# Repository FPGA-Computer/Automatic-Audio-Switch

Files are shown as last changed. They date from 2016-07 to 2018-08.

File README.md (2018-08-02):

"Automatic audio source switching"

This is the repository for this project.

Project page:
http://hw-by-design.blogspot.com/2018/08/automatic-audio-source-switching.html

Schematic tool: Eagle CAD 6.5.0
3D modelling: Sketchup 14.1 2014

The main PCB is for single sided toner transfer.  If you wish to make a double sided
PCB, just copy the ground pour from the secondardy side to primary side.  I have already
defined a ground split on tRestrict layer.

Licensing:
Schematic: Creative Commons 4.0 Attribution-ShareAlike 4.0 International
PCB & Layout: Creative Commons 4.0 Attribution-NonCommercial
3D modelling: Creative Commons 4.0 Attribution-ShareAlike 4.0 International

Creative Commons 4.0 Attribution-NonCommercial:
See http://creativecommons.org/licenses/by-nc/4.0/

Creative Commons 4.0 Attribution-ShareAlike 4.0 International
See http://creativecommons.org/licenses/by-sa/4.0/

Firmware (Keil MDK)
license: GPL 3.0

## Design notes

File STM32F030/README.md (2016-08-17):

"Automatic audio source switching"

file: startup_stm32f030.s, intfft.c and intfft.h 
are not mine and they have their own licenses.

The rest of the firmware is under GPL 3.0

release log:

Aug 17, 2016 - pre-release
My PCB order has been lost in the mail twice in a row so far
and it has been holding up the progress of this project.

I don't know when I'll have final hardware for full testing.

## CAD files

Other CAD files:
Eagle CAD/Sketchup 3D/daughtercard-assembly.skp
Eagle CAD/Sketchup 3D/daughtercard.skp

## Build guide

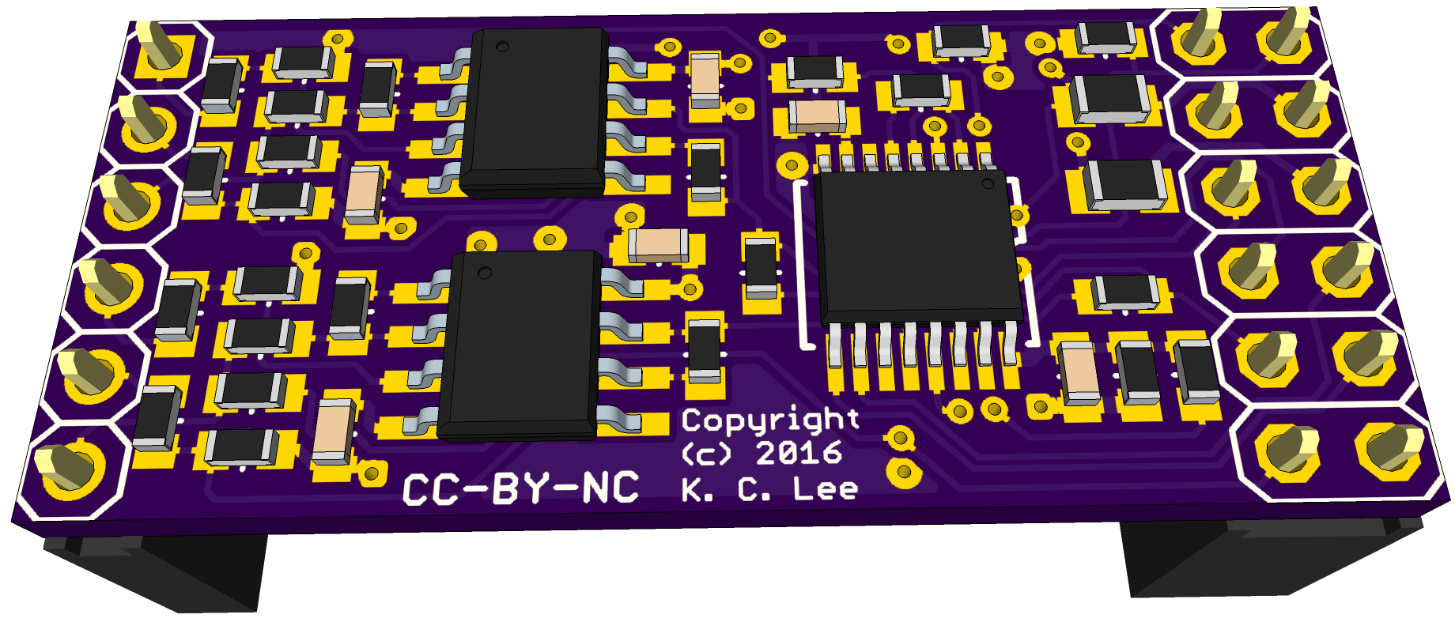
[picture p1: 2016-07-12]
Eagle CAD/Sketchup 3D/daughtercard-assembly.png

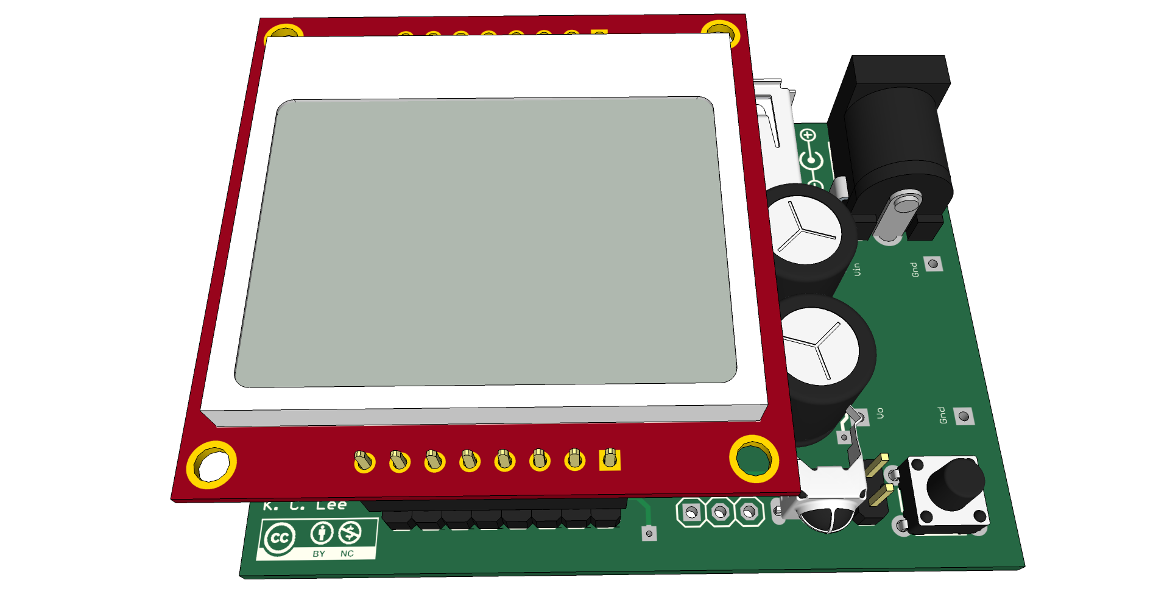
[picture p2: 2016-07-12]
Eagle CAD/Sketchup 3D/assembly.png

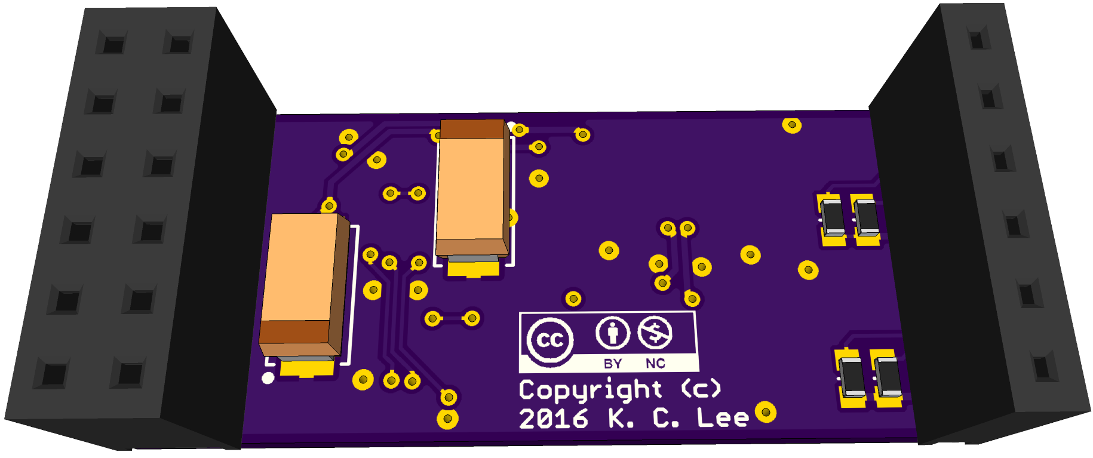
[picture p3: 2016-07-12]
Eagle CAD/Sketchup 3D/daughtercard-assembly-bot.png

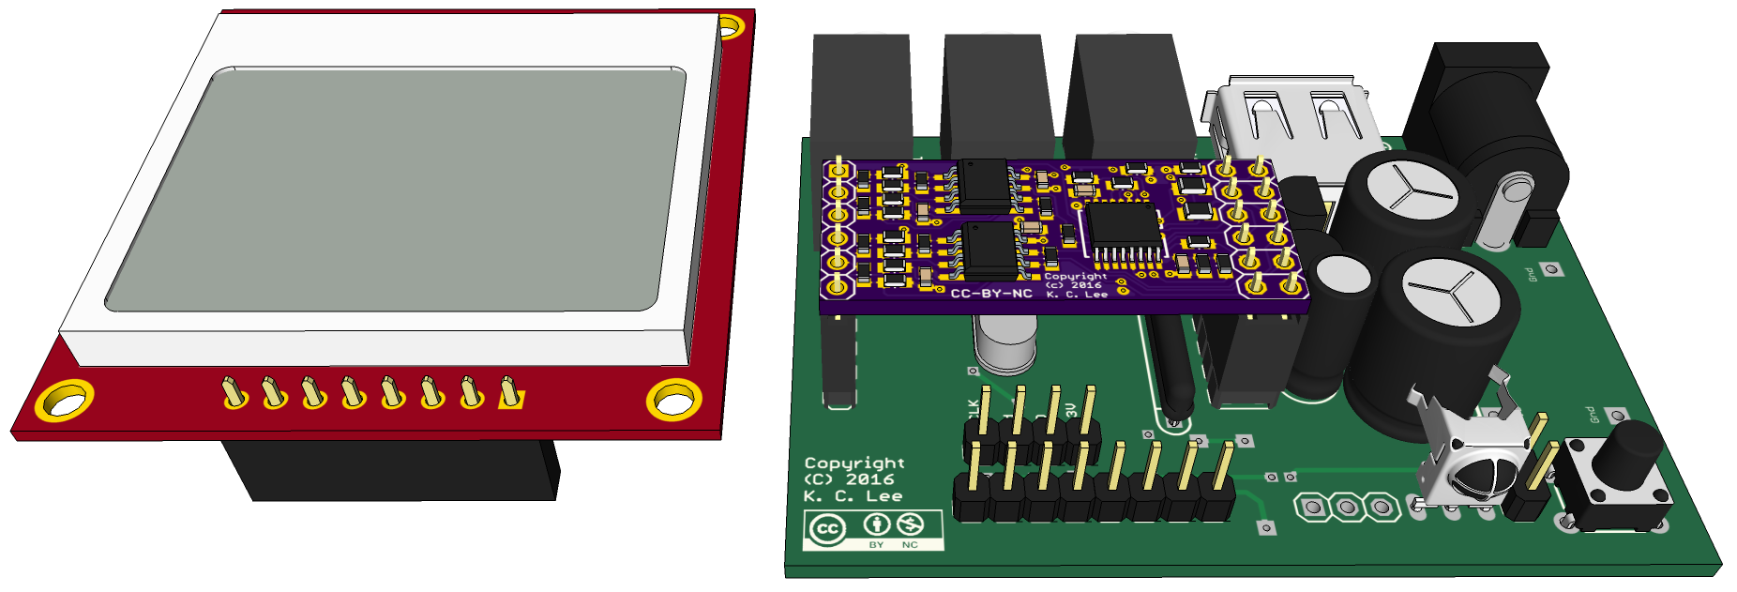
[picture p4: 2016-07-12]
Eagle CAD/Sketchup 3D/assembly exploded view.png

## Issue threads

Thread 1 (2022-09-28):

Hack a day links broken

spuder, 2022-09-28:
Thanks so much for sharing this project. It is very similar to what I want.

The links on hack a day appear to be broken

https://hackaday.io/project/12133-automatic-audio-source-switching

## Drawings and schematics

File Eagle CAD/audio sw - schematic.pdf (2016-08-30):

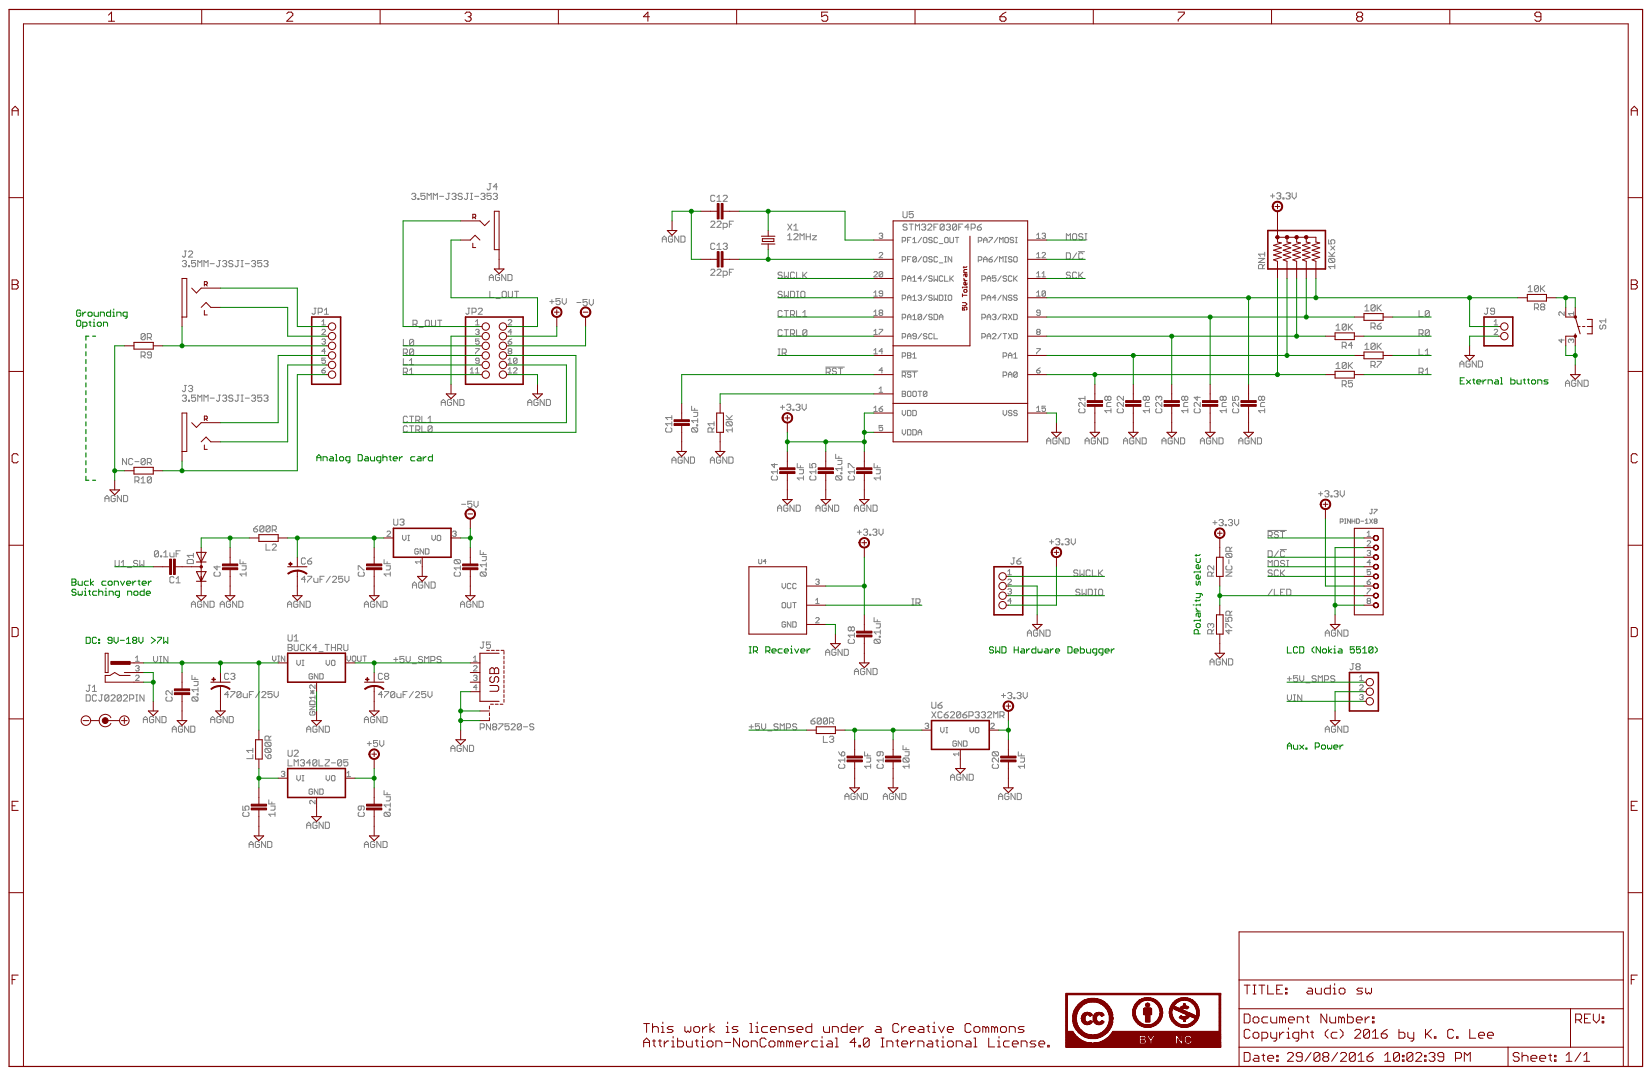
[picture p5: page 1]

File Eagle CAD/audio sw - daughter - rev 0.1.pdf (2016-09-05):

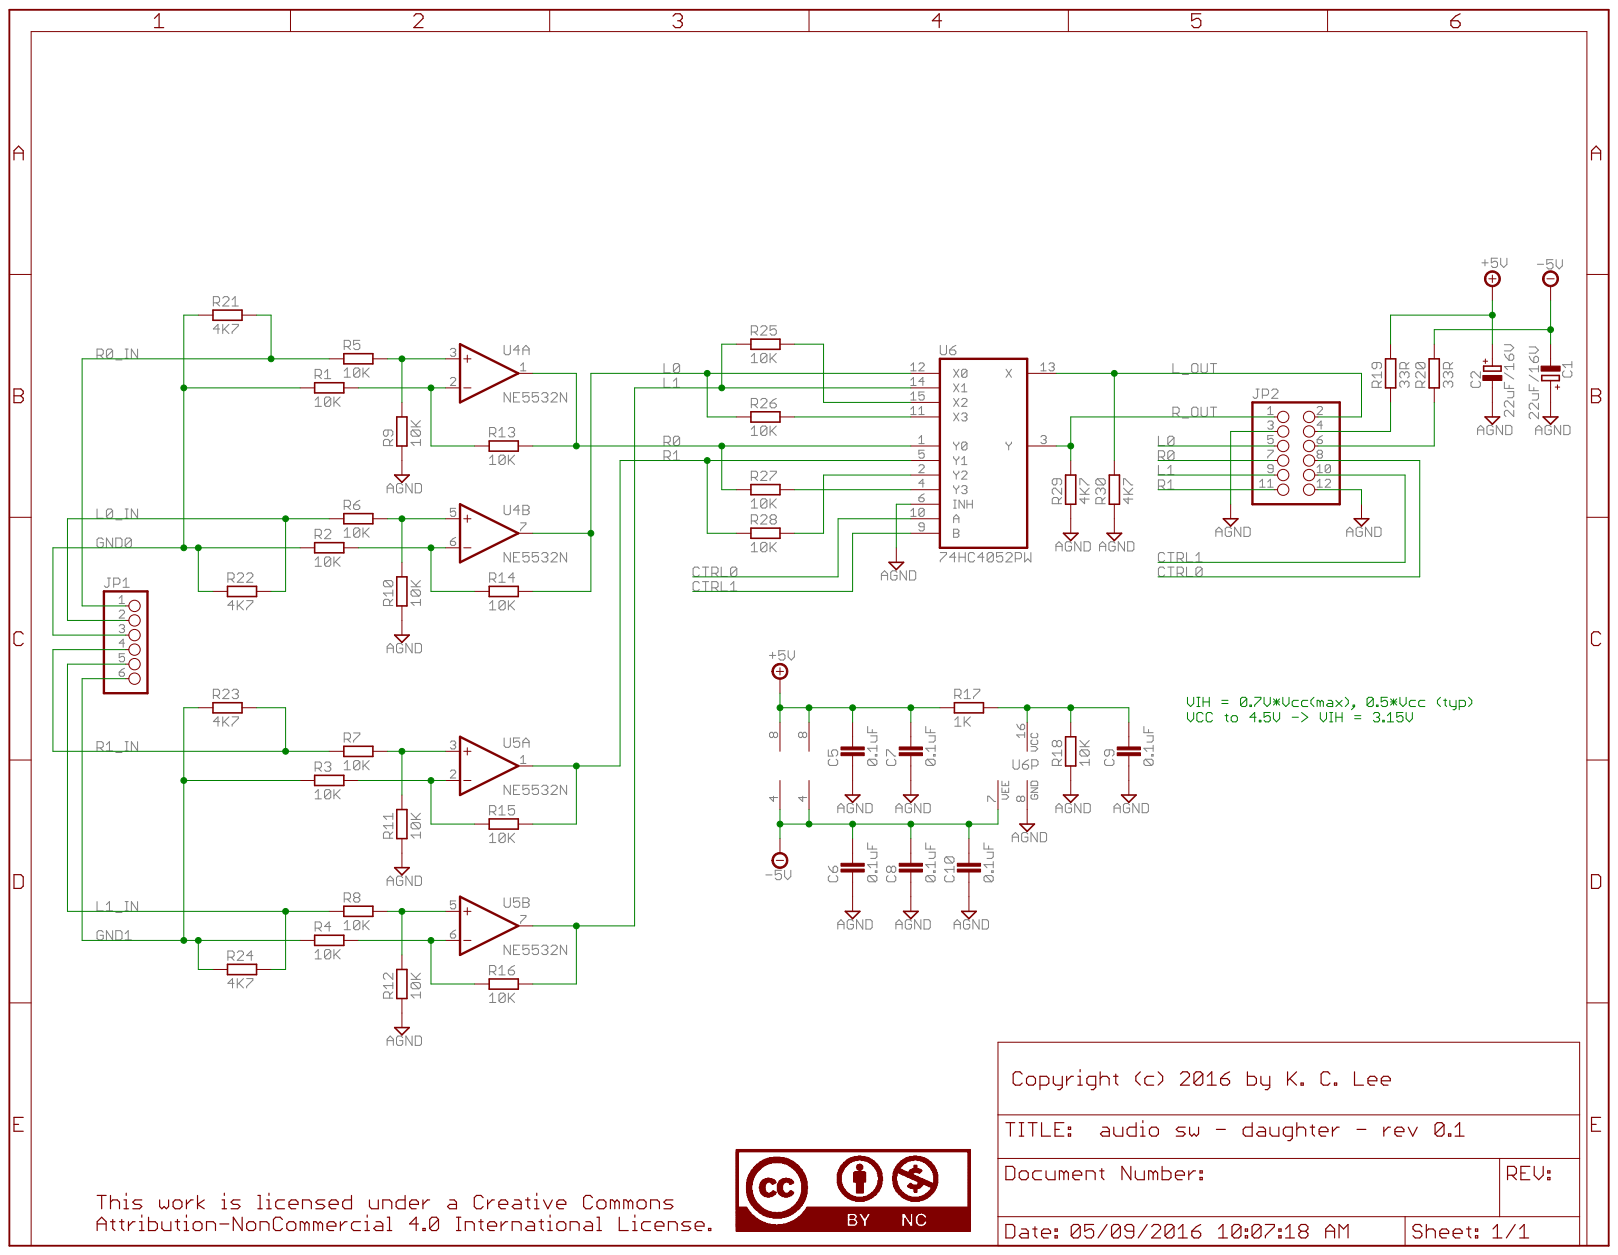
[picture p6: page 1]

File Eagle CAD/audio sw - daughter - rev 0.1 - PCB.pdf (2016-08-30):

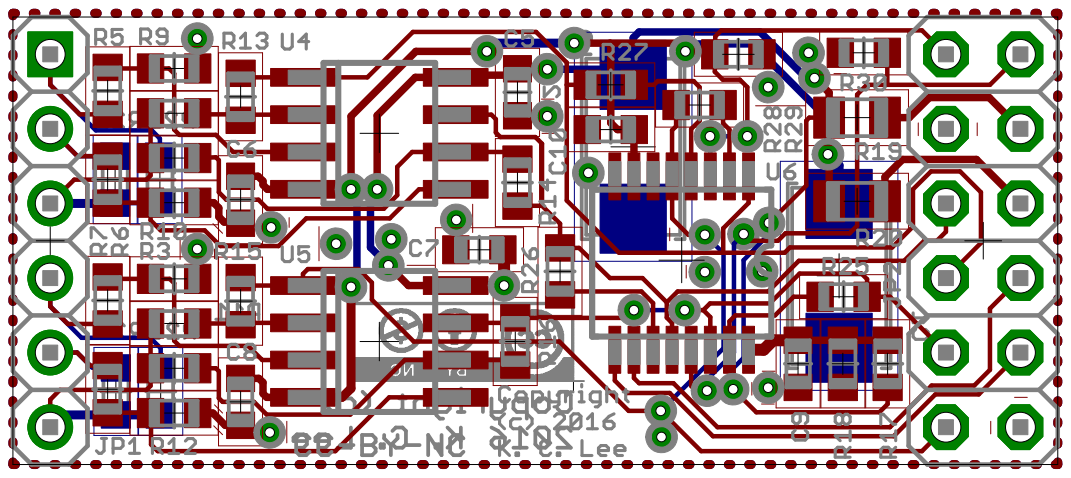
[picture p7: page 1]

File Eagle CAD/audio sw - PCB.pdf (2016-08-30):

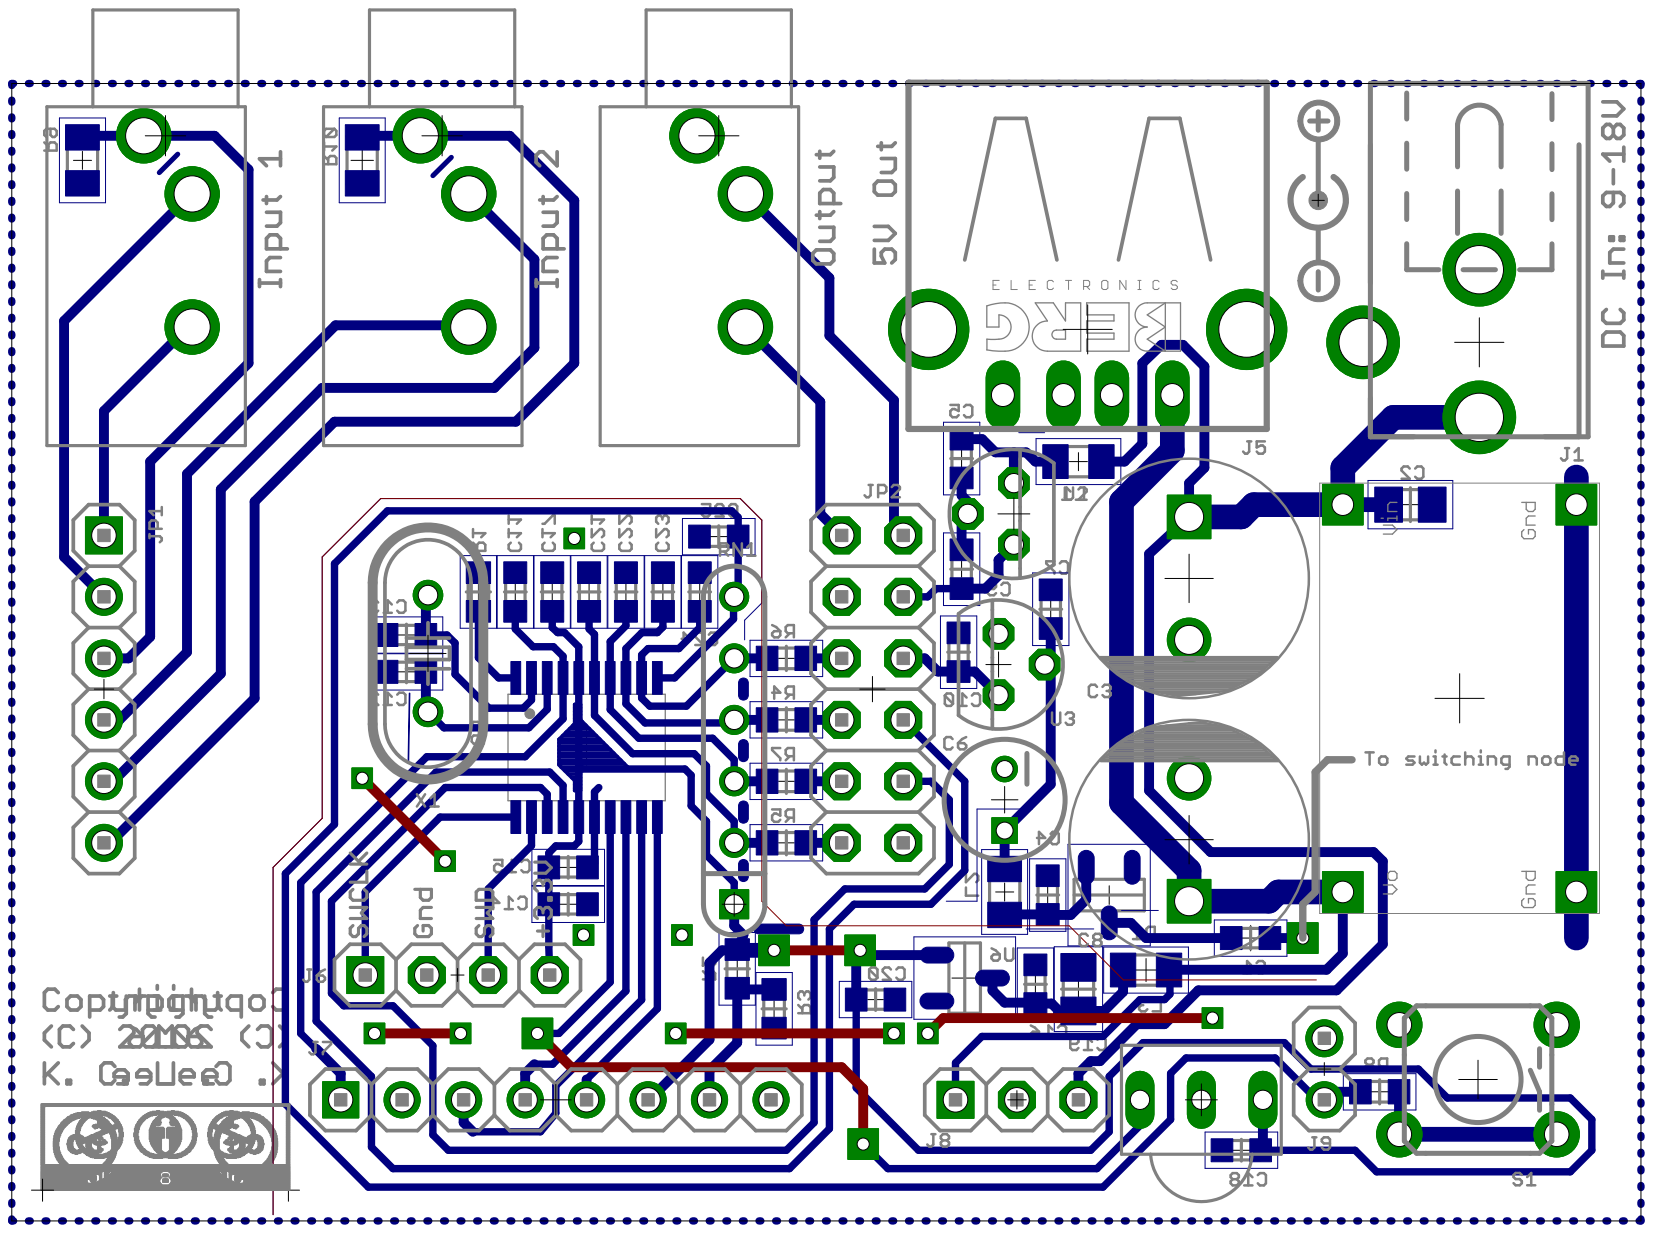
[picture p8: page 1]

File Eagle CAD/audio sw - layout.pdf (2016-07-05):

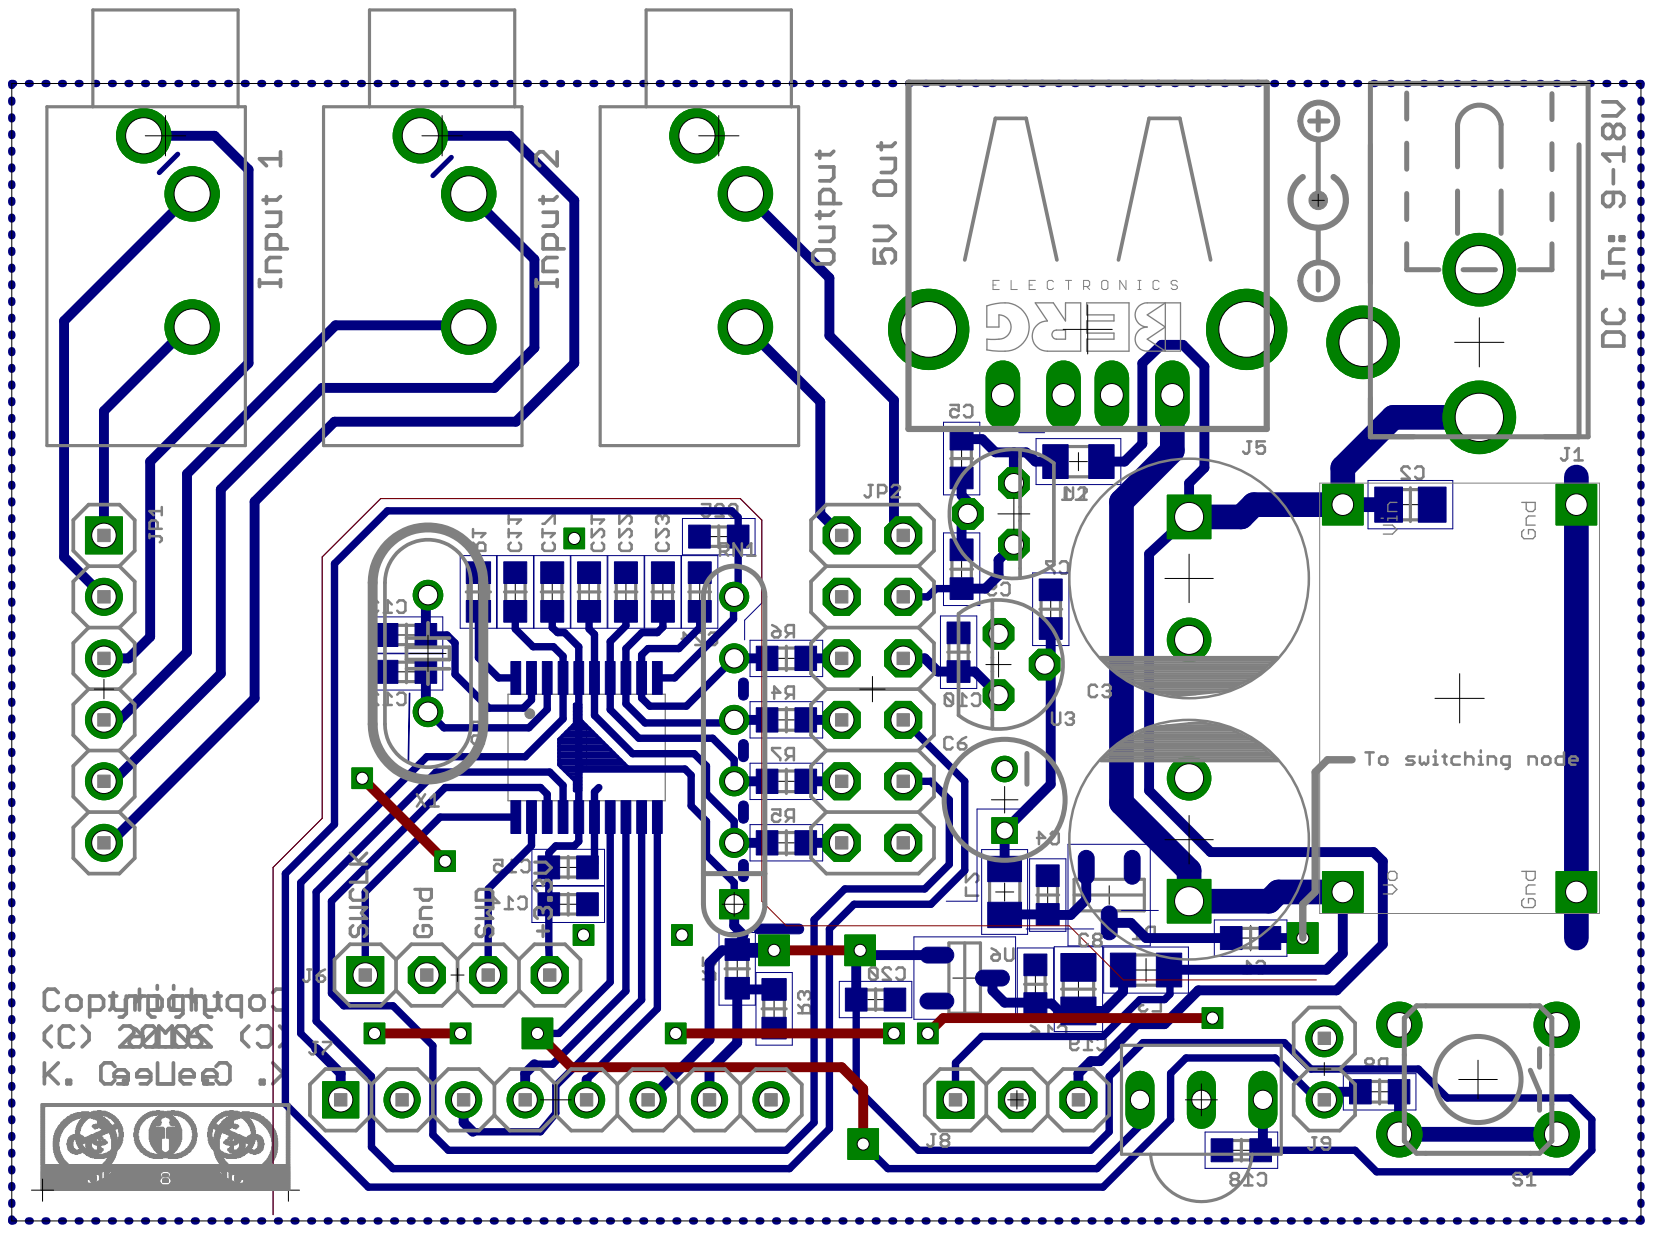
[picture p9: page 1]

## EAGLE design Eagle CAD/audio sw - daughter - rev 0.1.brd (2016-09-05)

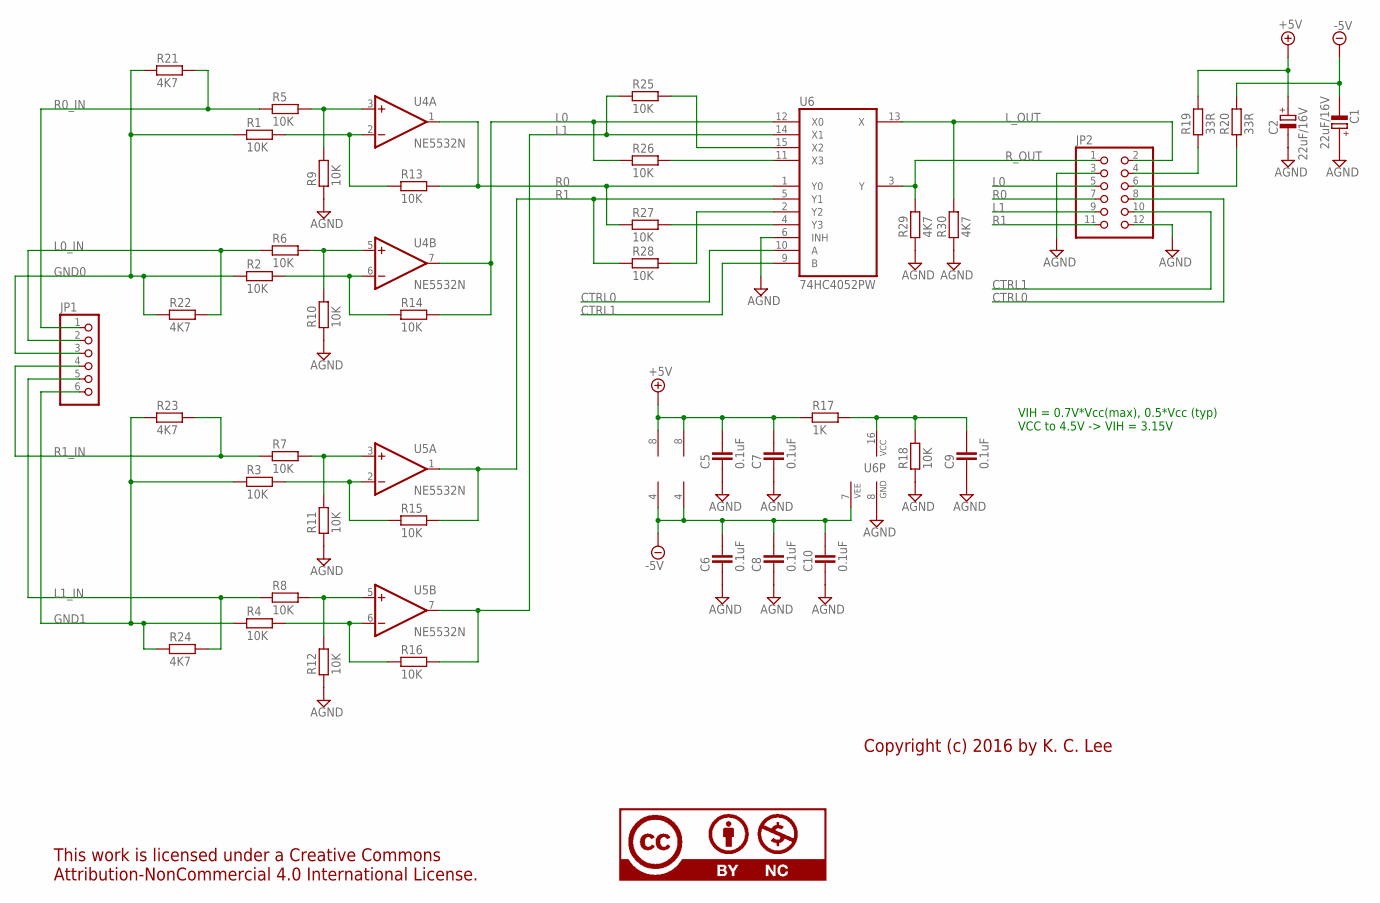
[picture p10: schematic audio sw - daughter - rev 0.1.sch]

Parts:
C1, C2: 22uF/16V; CAPMP6032X280N; PARTNO *
C5, C6, C7, C8, C9, C10: 0.1uF; CAPC1608X92N; PARTNO *
JP1: PINHD-1X6; 1X06; PARTNO *
JP2: PINHD-2X6_2.54; 2X06; PARTNO *
LICENSE1: CC-BY-NC75%; CC-BY-NC-75; PARTNO *
R1, R2, R3, R4, R5, R6, R7, R8, R9, R10, R11, R12, R13, R14, R15, R16, R18, R25, R26, R27, R28: 10K; RESC1608X55N; PARTNO *
R17: 1K; RESC1608X55N; PARTNO *
R19, R20: 33R; RESC2012X70N; PARTNO *
R21, R22, R23, R24, R29, R30: 4K7; RESC1608X55N; PARTNO *
U4, U5: NE5532N; SO08; PARTNO *
U6: 74HC4052PW; TSSOP16; PARTNO *

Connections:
+5V: C2.+, C5.2, C7.2, R17.1, R19.2, U4.8 (V+), U5.8 (V+)
-5V: C1.-, C6.2, C8.2, C10.2, R20.2, U4.4 (V-), U5.4 (V-), U6.7 (VEE)
AGND: C1.+, C2.-, C5.1, C6.1, C7.1, C8.1, C9.1, C10.1, JP2.3, JP2.12, R9.1, R10.1, R11.1, R12.1, R18.1, R29.1, R30.1, U6.6 (INH), U6.8 (GND)
CTRL0: JP2.8, U6.10 (A)
CTRL1: JP2.10, U6.9 (B)
GND0: JP1.3, R1.1, R2.1, R21.1, R22.1
GND1: JP1.6, R3.1, R4.1, R23.1, R24.1
L0: JP2.5, R14.2, R26.1, U4.7 (OUT), U6.12 (X0)
L0_IN: JP1.2, R6.1, R22.2
L1: JP2.9, R16.2, R25.1, U5.7 (OUT), U6.14 (X1)
L1_IN: JP1.5, R8.1, R24.2
L_OUT: JP2.2, R30.2, U6.13 (X)
unnamed: R5.2, R9.2, U4.3 (+IN)
unnamed: R1.2, R13.1, U4.2 (-IN)
unnamed: C9.2, R17.2, R18.2, U6.16 (VCC)
unnamed: R26.2, U6.11 (X3)
unnamed: R25.2, U6.15 (X2)
unnamed: R6.2, R10.2, U4.5 (+IN)
unnamed: R2.2, R14.1, U4.6 (-IN)
unnamed: JP2.4, R19.1
unnamed: R27.2, U6.4 (Y3)
unnamed: JP2.6, R20.1
unnamed: R7.2, R11.2, U5.3 (+IN)
unnamed: R3.2, R15.1, U5.2 (-IN)
unnamed: R28.2, U6.2 (Y2)
unnamed: R8.2, R12.2, U5.5 (+IN)
unnamed: R4.2, R16.1, U5.6 (-IN)
R0: JP2.7, R13.2, R27.1, U4.1 (OUT), U6.1 (Y0)
R0_IN: JP1.1, R5.1, R21.2
R1: JP2.11, R15.2, R28.1, U5.1 (OUT), U6.5 (Y1)
R1_IN: JP1.4, R7.1, R23.2
R_OUT: JP2.1, R29.2, U6.3 (Y)

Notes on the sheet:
VIH = 0.7V*Vcc(max), 0.5*Vcc (typ) VCC to 4.5V -> VIH = 3.15V
Copyright (c) 2016 by K. C. Lee

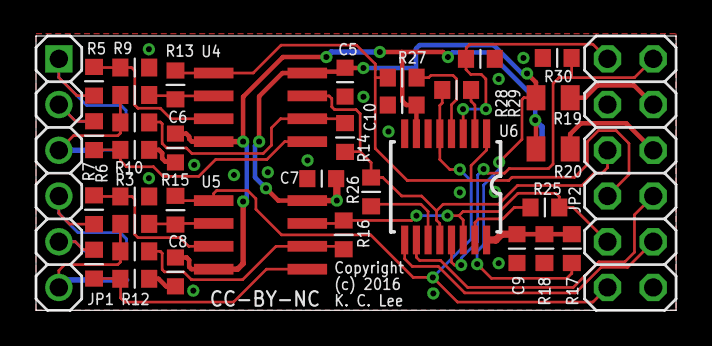
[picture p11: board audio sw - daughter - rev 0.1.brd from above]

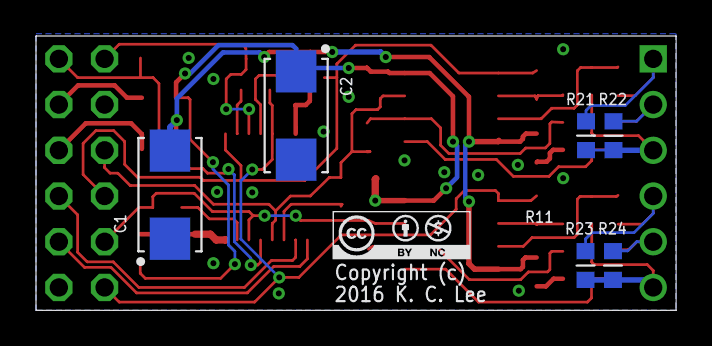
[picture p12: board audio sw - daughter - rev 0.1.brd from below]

Board: 2 copper layers, 35.6 x 15.2 mm, 44 parts (7 on the bottom side), 32 nets.

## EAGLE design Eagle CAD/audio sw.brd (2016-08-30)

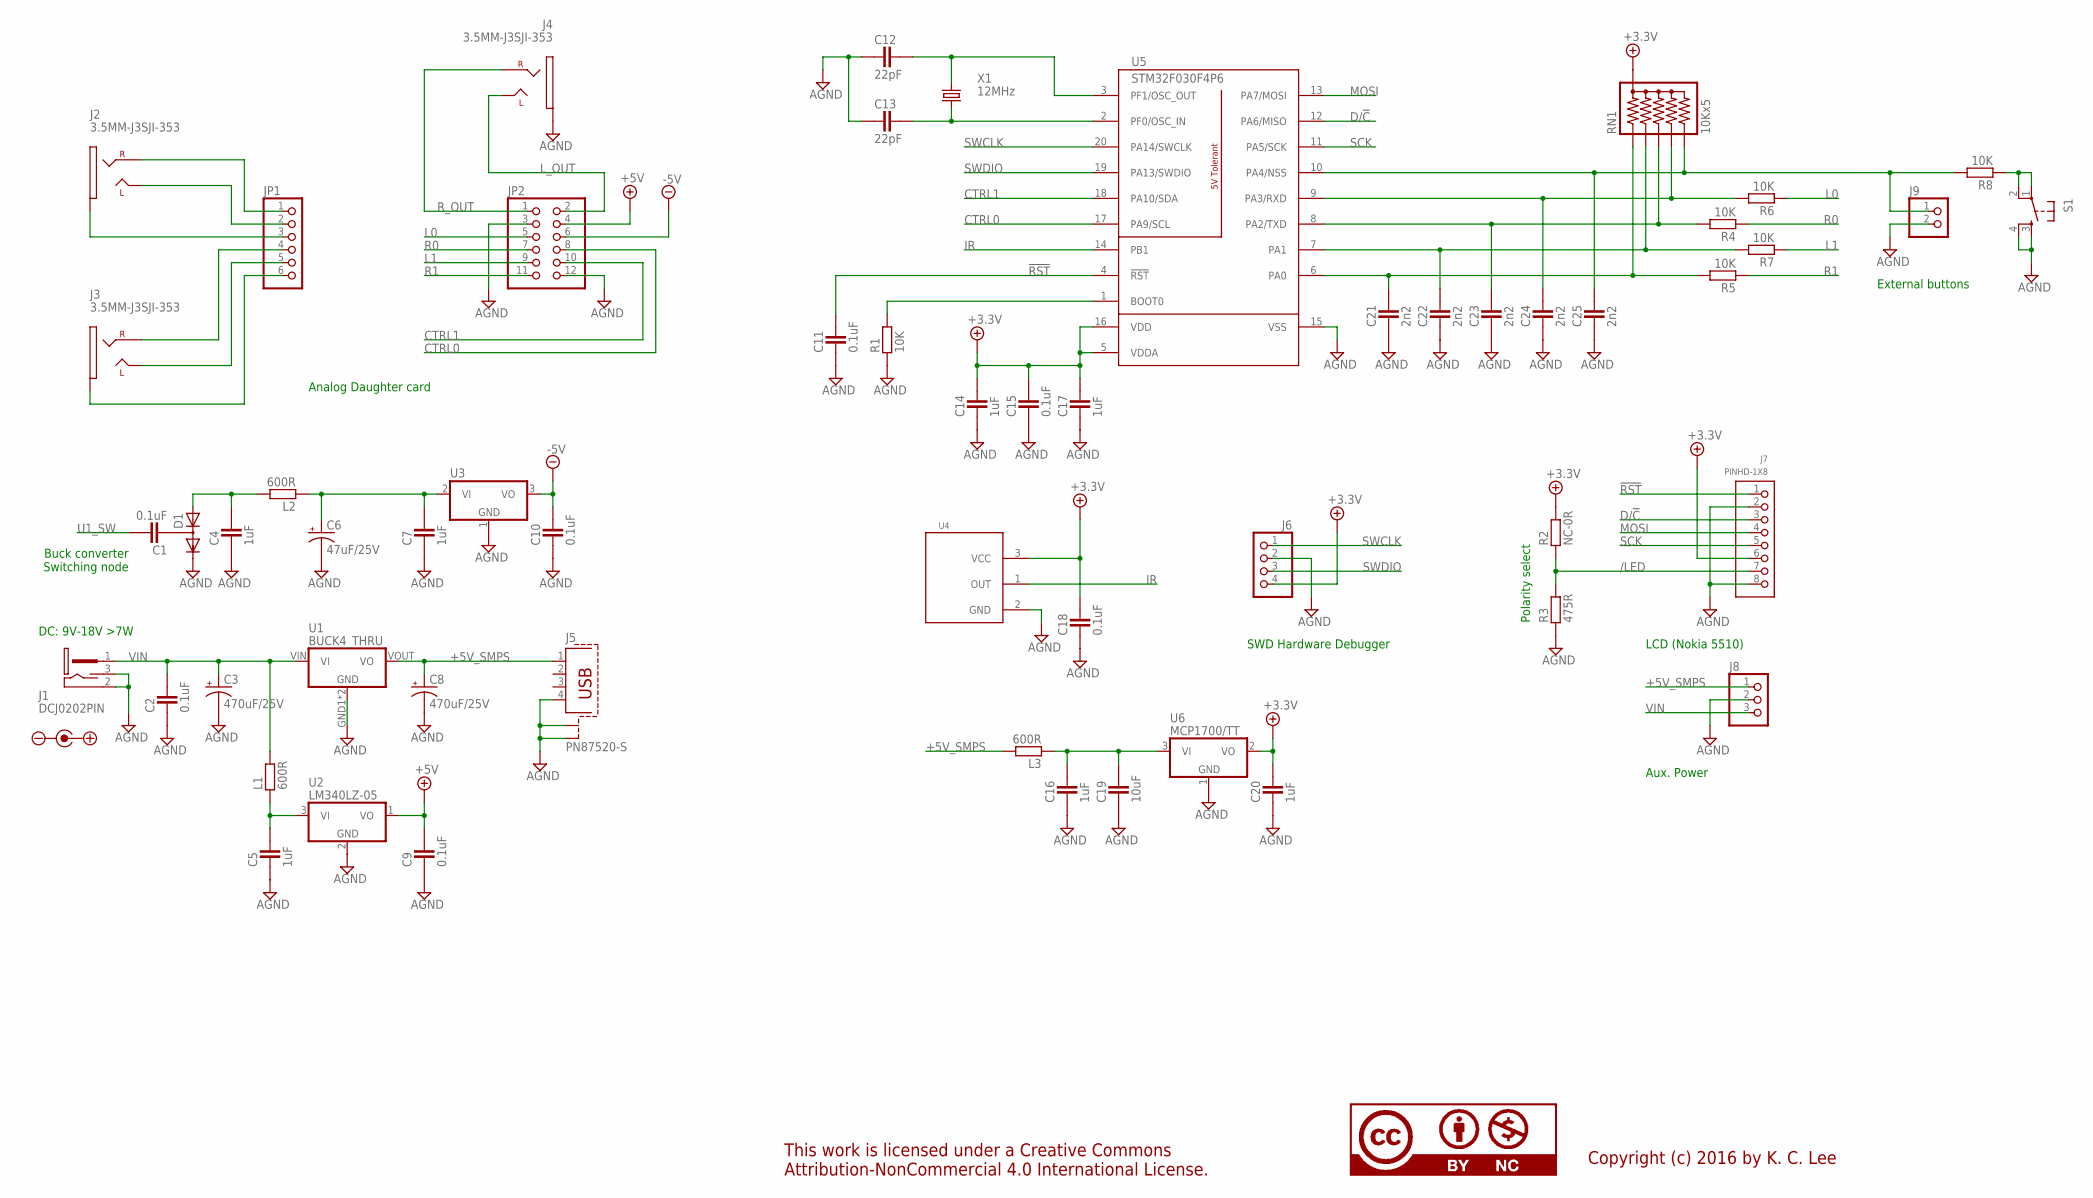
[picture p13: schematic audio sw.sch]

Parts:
$1_40_$: CC-BY-NC100%; CC-BY-NC-100
C1, C9, C10, C11, C15, C18: 0.1uF; CAPC1608X92N
C2: 0.1uF; CAPC2012X145AN
C3, C8: 470uF/25V; CPOL-RADIAL-470UF-25V
C4, C5, C7, C14, C16, C17, C20: 1uF; CAPC1608X92N
C6: 47uF/25V; CPOL-RADIAL-10UF-25V
C12, C13: 22pF; CAPC1608X92N
C19: 10uF; CAPC2012X145AN
C21, C22, C23, C24, C25: 2n2; CAPC1608X92N
D1: KA2KA_SOT-23; SOT95P280X135-3N
J1: DCJ0202PIN; PJ-102A
J2, J3, J4: 3.5MM-J3SJI-353; CUI-3MM
J5: PN87520-S
J6: PINHD-1X4_2.54; 1X04
J7: PINHD-1X8; 1X08
J8: PINHD-1X3; 1X03
J9: PINHD-1X2_2.54; 1X02
JP1: PINHD-1X6; 1X06
JP2: PINHD-2X6_2.54; 2X06
L1, L2, L3: 600R; RESC2012X70N
R1, R4, R5, R6, R7, R8: 10K; RESC1608X55N
R2: NC-0R; RESC1608X55N
R3: 475R; RESC1608X55N
RN1: 10Kx5; RPACK-SIP-PTH-5
S1: TAC_SWITCHPTH; TACTILE-PTH
U1: BUCK4_THRU; PWR4_THRU
U2: LM340LZ-05; TO92-CLP
U3: 79L05Z; TO92-CLP
U4: AX-1838HS; AX1838
U5: STM32F030F4P6; TSSOP20
U6: MCP1700/TT; SOT95P280X135-3N
U$1: POLARITY
X1: 12MHz; HC49U-V

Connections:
!RST: C11.2, J7.1, U5.4 (!RST)
+3.3V: C14.2, C15.2, C17.2, C18.2, C20.2, J6.4, J7.6, R2.2, RN1.P$1 (1), U4.3 (VCC), U5.5 (VDDA), U5.16 (VDD), U6.2 (VO)
+5V: C9.2, JP2.4, U2.1 (VO)
+5V_SMPS: C8.+, J5.1, J8.1, L3.2, U1.VOUT (VO)
-5V: C10.2, JP2.6, U3.3 (VO)
/LED: J7.7, R2.1, R3.2
AGND: C2.1, C3.-, C4.1, C5.1, C6.2 (-), C7.1, C8.-, C9.1, C10.1, C11.1, C12.1, C13.1, C14.1, C15.1, C16.1, C17.1, C18.1, C19.1, C20.1, C21.1, C22.1, C23.1, C24.1, C25.1, D1.2 (K), J1.2 (3), J1.3 (2), J4.1, J5.4, J5.S1, J5.S2, J6.2, J7.2, J7.8, J8.2, J9.2, JP2.3, JP2.12, R1.1, R3.1, S1.3, S1.4, U1.GND1 (GND), U1.GND2 (GND), U2.2 (GND), U3.1 (GND), U4.2 (GND), U5.15 (VSS), U6.1 (GND); also elsewhere on the board
CTRL0: JP2.8, U5.17 (PA9/SCL)
CTRL1: JP2.10, U5.18 (PA10/SDA)
D/!C: J7.3, U5.12 (PA6/MISO)
IR: U4.1 (OUT), U5.14 (PB1)
L0: JP2.5, R6.1
L1: JP2.9, R7.1
L_OUT: J4.2 (5), JP2.2
MOSI: J7.4, U5.13 (PA7/MOSI)
unnamed: C16.2, C19.2, L3.1, U6.3 (VI)
unnamed: J2.3 (2), JP1.1
unnamed 17: J2.1, JP1.3; also elsewhere on the board
unnamed: J2.2 (5), JP1.2
unnamed: J3.3 (2), JP1.4
unnamed 20: J3.1, JP1.6; also elsewhere on the board
unnamed: J3.2 (5), JP1.5
unnamed: C5.2, L1.1, U2.3 (VI)
unnamed: R8.1, S1.1, S1.2
unnamed: C6.1 (+), C7.2, L2.1, U3.2 (VI)
unnamed: C1.1, D1.3 (KA)
unnamed: C4.2, D1.1 (A), L2.2
unnamed: R1.2, U5.1 (BOOT0)
unnamed: C21.2, R5.2, RN1.P$2 (2), U5.6 (PA0)
unnamed: C22.2, R7.2, RN1.P$3 (3), U5.7 (PA1)
unnamed: C23.2, R4.2, RN1.P$4 (4), U5.8 (PA2/TXD)
unnamed: C24.2, R6.2, RN1.P$5 (5), U5.9 (PA3/RXD)
unnamed: C25.2, J9.1, R8.2, RN1.P$6 (6), U5.10 (PA4/NSS)
unnamed: C13.2, U5.2 (PF0/OSC_IN), X1.1
unnamed: C12.2, U5.3 (PF1/OSC_OUT), X1.2
R0: JP2.7, R4.1
R1: JP2.11, R5.1
R_OUT: J4.3 (2), JP2.1
SCK: J7.5, U5.11 (PA5/SCK)
SWCLK: J6.1, U5.20 (PA14/SWCLK)
SWDIO: J6.3, U5.19 (PA13/SWDIO)
U1_SW: C1.2
VIN: C2.2, C3.+, J1.1, J8.3, L1.2, U1.VIN (VI)

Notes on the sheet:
Buck converter Switching node
DC: 9V-18V >7W
Polarity select
External buttons
SWD Hardware Debugger
Aux. Power
LCD (Nokia 5510)
Copyright (c) 2016 by K. C. Lee
Analog Daughter card

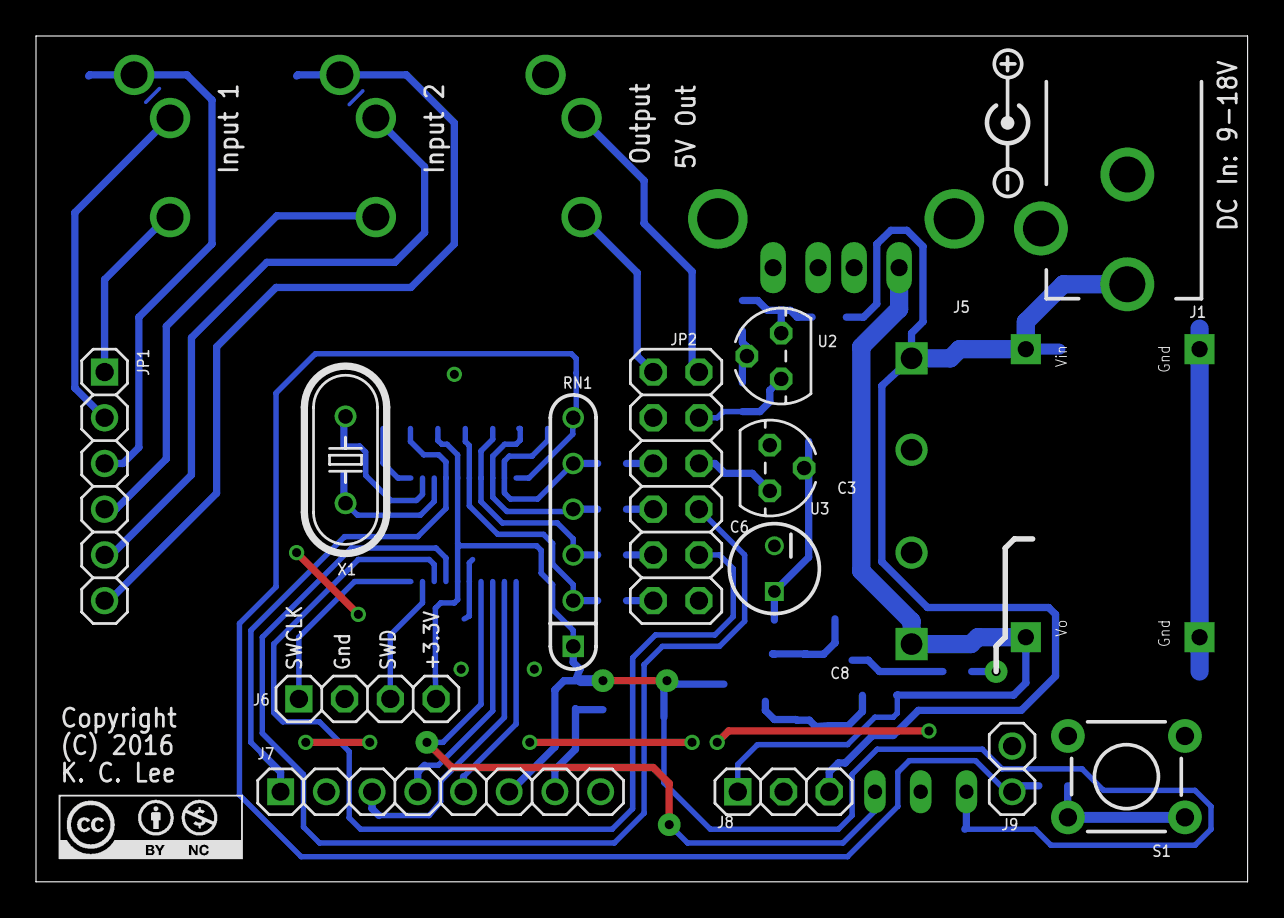
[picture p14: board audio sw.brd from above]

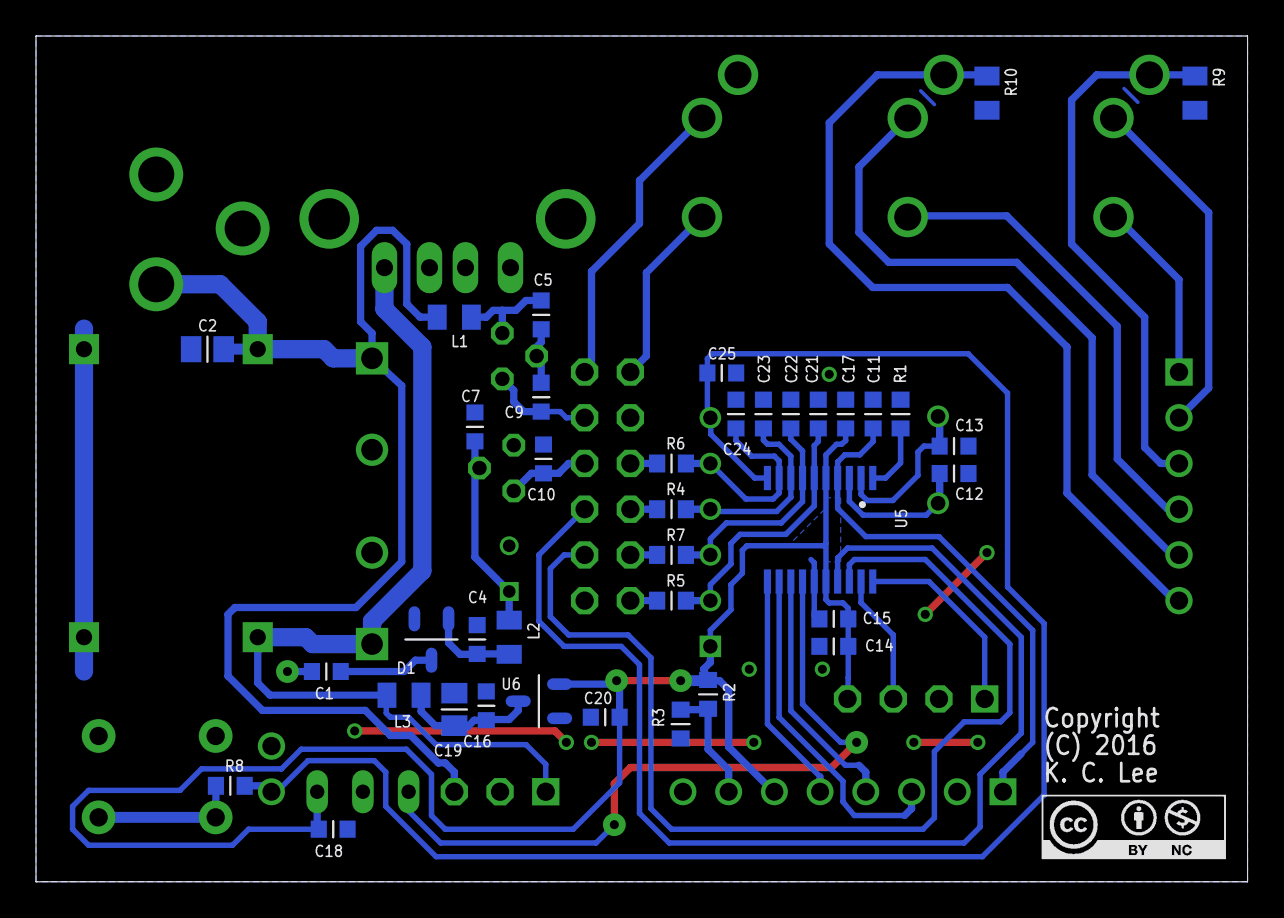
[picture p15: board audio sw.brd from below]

Board: 2 copper layers, 67.3 x 47.0 mm, 62 parts (39 on the bottom side), 42 nets.

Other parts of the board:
LICENSE1: CC-BY-NC100%; CC-BY-NC-100
R9: 0R; RESC2012X70N
R10: NC-0R; RESC2012X70N

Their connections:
AGND: R9.2, R10.2; also elsewhere on the board
unnamed 17: R9.1; also elsewhere on the board
unnamed 20: R10.1; also elsewhere on the board

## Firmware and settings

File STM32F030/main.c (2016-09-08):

/*
 * main.c
 *
 * Created: June-16-16, 8:38:27 AM
 *  Author: K. C. Lee
 * Copyright (c) 2016 by K. C. Lee
 
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
	If not, see http://www.gnu.org/licenses/gpl-3.0.en.html
 */ 

#include "hardware.h"
#include "font.h"

uint32_t Prev_Time=0xffff;
uint8_t Ticks;

int main(void)
{ 
	Hardware_Init();
	Audio_Init();
	ChangeDisplayMode(/*VU_Mode*/Spectrum_Mode);
	ADC_Start();
	
	while(1)
	{	
		__WFI( 	);
		if(Audio_Data.Conv_Done)
		{ 		
			Audio_Data.Conv_Done = 0;
			
			Audio_Processing();
			UpdateDisplay();
		}
		
		if(FIFO_ReadAvail((FIFO*)IR_Buf))
		{
			Getc((FIFO*)IR_Buf);
		}
	}
}

void UpdateDisplay(void)
{
	if(Ticks)
		Ticks--;
	else
	{
		Ticks = TICK_RELOAD;
		UpdateTime();		
		Update_AudioSource();
		
		switch(Audio_Data.Display_Mode)
		{
			case VU_Mode:
				Draw_VUBars();	
				break;
			case Spectrum_Mode:
				Plot_Spectrum();
				break;
		}	
	}
}

void ChangeDisplayMode(uint8_t Mode)
{
	LCD_Cls();
	Audio_Data.Display_Mode = Mode;
	
	if(Audio_Data.Display_Mode==VU_Mode)
	{	
		Draw_AudioSource_Label();
		Draw_VU_Legend();
	}
}

void UpdateTime(void)
{		
	if(Prev_Time != RTC->TR)
	{
		Prev_Time = RTC->TR;
		LCD_Home();
		
		if(Audio_Data.Display_Mode==VU_Mode)
		{
			RTC_PrintDate();
			LCD_PutCh(' ');
			RTC_PrintWeekDay(3);
			LCD_PutCh('\n');
		}
//		else
//			LCD_Moveto(0,RTC_ALT_ROW);
		
		RTC_PrintTime();
	}
}

void Draw_AudioSource_Label(void)
{	
	if(Audio_Data.Display_Mode==VU_Mode)
	{
		LCD_Moveto(AUDIO_SRC0_COL,AUDIO_SRC_ROW);
		LCD_Puts(AUDIO_SRC0_LABEL);
		LCD_Moveto(AUDIO_SRC1_COL,AUDIO_SRC_ROW);	
		LCD_Puts(AUDIO_SRC1_LABEL);
	}
}

void Audio_StateMachine(void)
{
	const uint32_t State_IO[] =
	{ 
		
//		PIN_SET(CTRL0),PIN_SET(CTRL0),PIN_SET(CTRL0),
//		PIN_CLR(CTRL0),PIN_CLR(CTRL0)
		
  	// Loudness protection
		PIN_SET(CTRL0)|PIN_CLR(CTRL1),
		PIN_SET(CTRL0)|PIN_CLR(CTRL1),PIN_CLR(CTRL0)|PIN_SET(CTRL1),
		PIN_CLR(CTRL0)|PIN_CLR(CTRL1),PIN_SET(CTRL0)|PIN_SET(CTRL1)
		
	};

	// State machine for switching
	switch(Audio_Data.State)
	{
		case Audio_Idle:
		case Audio_TV_Norm:
		case Audio_TV_Loud:
		  if(AUDIO_LOUDNESS_CH(Source_PC)==Audio_Loud)
				Audio_Data.State = Audio_PC_Loud;
			else if (AUDIO_LOUDNESS_CH(Source_PC)==Audio_Detect)
				Audio_Data.State = Audio_PC_Norm;
			else if (AUDIO_LOUDNESS_CH(Source_TV)==Audio_Loud)
				Audio_Data.State = Audio_TV_Loud;
			else if (AUDIO_LOUDNESS_CH(Source_TV)==Audio_Detect)
				Audio_Data.State = Audio_TV_Norm;
			break;
			
		case Audio_PC_Norm:
		case Audio_PC_Loud:
		  if(AUDIO_LOUDNESS_CH(Source_PC)==Audio_Loud)
				Audio_Data.State = Audio_PC_Loud;
			else if (AUDIO_LOUDNESS_CH(Source_PC)==Audio_Detect)
				Audio_Data.State = Audio_PC_Norm;			
			else if (AUDIO_LOUDNESS_CH(Source_PC)==Audio_None)			
				Audio_Data.State = Audio_Idle;
			break;
	}

	GPIOA->BSRR = State_IO[Audio_Data.State];
	
	Audio_Data.Selected = ((Audio_Data.State == Audio_TV_Norm)||
												 (Audio_Data.State == Audio_TV_Loud))?1:0;
}

void Update_AudioSource(void)
{
	uint8_t i;
	
  const uint8_t Audio_Detect_Char[] =
	{ ' ',SYMBOL_SOUND_MAYBE,SYMBOL_SOUND_ON,SYMBOL_SOUND_LOUD };
	
	Audio_StateMachine();

	if(Audio_Data.Display_Mode==VU_Mode)
	{	
		for(i=0;i<ADC_MAX_SRC;i++)
		{
			LCD_Moveto(i*AUDIO_SRC_COL,AUDIO_SRC_ROW);
		  LCD_PutCh((Audio_Data.State==Audio_Idle)?' ':
								(Audio_Data.Selected==i)?SYMBOL_SPEAKER:' ');		
			LCD_PutCh(Audio_Detect_Char[AUDIO_LOUDNESS_CH(i)]);			
		}
	}
	else
	{
		LCD_Moveto(AUDIO_SRC_ALT_COL,AUDIO_SRC_ALT_ROW);
		LCD_PutCh((Audio_Data.State==Audio_Idle)?' ':SYMBOL_SPEAKER);
		LCD_PutCh(Audio_Detect_Char[AUDIO_LOUDNESS_CH(Audio_Data.Selected)]);
		LCD_Puts(Audio_Data.Selected?AUDIO_SRC1_LABEL:AUDIO_SRC0_LABEL);
	}
}

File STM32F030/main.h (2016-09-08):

/*
 * hardware.h
 *
 * Created: July-10-16, 4:09:33 PM
 *  Author: K. C. Lee
 * Copyright (c) 2016 by K. C. Lee 
 
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
	If not, see http://www.gnu.org/licenses/gpl-3.0.en.html
 */ 

#ifndef _MAIN_H_
#define _MAIN_H_

#include <stdint.h>
#include "stm32f0xx.h"
#include "core_cm0.h"
#include <string.h>

void Task_Update_Volume(void);
void Task_ADC_Sample(void);
void UpdateTime(void);
void UpdateDisplay(void);
void ChangeDisplayMode(uint8_t Mode);
void Update_AudioSource(void);
void Draw_AudioSource_Label(void);

enum Display_Mode
{ Spectrum_Mode, VU_Mode };

#define AUDIO_SRC0_LABEL			"PC"
#define AUDIO_SRC1_LABEL			"TV"

// Time separator
#define TIME_SEPARATOR  			':'
// Date separator
#define DATE_SEPARATOR  			'-'

// 12 hours format
#define RTC_FORMAT_12HR

// Volume average time in ms
#define VOLUME_AVERAGE_PERIOD	300
// Peak volume decay time in ms
#define PEAK_VOLUME_DECAY			1500

#define ADC_AUDIO_SAMPLES			256
#define ADC_BLOCK_SIZE				(ADC_AUDIO_SAMPLES/2)
#define N_FFT									ADC_BLOCK_SIZE

#define ADC_SAMPLE_RATE				38400UL
#define ADC_SAMPLE_PERIOD			(CPU_CLOCK/ADC_SAMPLE_RATE)

#define ADC_DMA_IRQ_RATE			(ADC_SAMPLE_RATE/ADC_BLOCK_SIZE)
#define SCREEN_REFRESH_RATE		15UL
#define TICK_RELOAD						(ADC_DMA_IRQ_RATE/SCREEN_REFRESH_RATE)

#define AUDIO_TIMEOUT					1000
#define LOUDNESS_TIMEOUT			1000
#define AUDIO_COUNTDOWN_TH		(AUDIO_TIMEOUT/2)				

#define AUDIO_THRESHOLD 			0x94L
#define LOUDNESS_THRESHOLD		0x005F8E

extern uint32_t Prev_Time;
extern uint8_t Ticks;

#define RTC_COL						4
#define RTC_DATE_ROW			0
#define RTC_TIME_ROW			1
#define RTC_ALT_ROW				0

#define AUDIO_SRC0_COL		3
#define AUDIO_SRC1_COL		10
#define AUDIO_SRC_ROW			2
#define AUDIO_SRC_COL			7

#define AUDIO_SRC_ALT_COL 10
#define AUDIO_SRC_ALT_ROW RTC_ALT_ROW

#define VU_COL						5
#define VU_L_ROW					3
#define VU_R_ROW					4
#define VU_LEGEND_Y				5

// Alternate VU bar
#define VU_BAR_WIDTH			3
#define VU_BAR_ALT_COL		1
#define VU_BAR_ALT_ROW		0
#define VU_BAR_MAJ_TIC		3

#define SPECTRUM_ROWS			5
#define SPECTRUM_ROW			1
#define SPECTRUM_COL			0

#define SPECTRUM_START		0
#define SPECTRUM_BIN			(LCD_MAX_X-SPECTRUM_WIDTH)
#undef	SPECTRUM_WIDEBAR 

#ifdef SPECTRUM_WIDEBAR
#define SPECTRUM_WIDTH		2
#else
#define SPECTRUM_WIDTH		1
#endif

#define SPECTRUM_VU_WIDTH	5
#define SPECTRUM_VU_COL		(LCD_MAX_X-(SPECTRUM_VU_WIDTH+1)*ADC_CH_PER_SRC)

#define MIN(X,Y)					(((X)<=(Y))?(X):(Y))
#define SPECTRUM_END			MIN(LCD_MAX_X,(ADC_BLOCK_SIZE/2-SPECTRUM_START)*SPECTRUM_WIDTH)

#undef SPECTRUM_AUTOSCALE

#define SCALE_VU					4
#define SCALE_SPECTRUM		8

#define BITMAP_PEAK				0x03
#define BITMAP_VU					0xaa
#define BITMAP_SPECTRUM		0xff

#endif

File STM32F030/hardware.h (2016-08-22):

/*
 * hardware.h
 *
 * Created: March-14-16, 4:52:17 PM
 *  Author: K. C. Lee
 * Copyright (c) 2016 by K. C. Lee 
 
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
	If not, see http://www.gnu.org/licenses/gpl-3.0.en.html
 */ 

#ifndef _HARDWARE_H_
#define _HARDWARE_H_

#include "main.h"
#include "gpio.h"

#define CPU_CLOCK					48000000UL
#define UART_BAUD					115200

#define HSE_CLOCK					12000000UL
#define HSE
#define HSE_BYPASS				0

// Enable Debug shell 
//#define DBG_SHELL
#undef DBG_SHELL

//#define ADC_RES_8
#define ADC_RES_12

// 12MHz clock x4 = 48MHz
#define CFGR_PLL_MULT					RCC_CFGR_PLLMUL4

#define LCD_DC								PA6
#define ADC_SRC_GROUP					(ADC_CHSELR_CHSEL0|ADC_CHSELR_CHSEL1|ADC_CHSELR_CHSEL2|ADC_CHSELR_CHSEL3|ADC_CHSELR_CHSEL4)

#define PEAK_DECAY_SAMPLES		((PEAK_VOLUME_DECAY*ADC_SAMPLE_RATE/ADC_BLOCK_SIZE)/1000)
#define ADC_AVERAGES					(VOLUME_AVERAGE_PERIOD*ADC_SAMPLE_RATE/ADC_BLOCK_SIZE/1000)

// Max # of audio source
#define ADC_MAX_SRC						2
// L/R channels
#define ADC_CH_PER_SRC				2
#define ADC_MAX_AUD_CH				(ADC_MAX_SRC*ADC_CH_PER_SRC)
// Max # of channels per conversion
#define ADC_MAX_CH						(ADC_MAX_AUD_CH+1)

#include "main.h"
#include "nokia5110.h"
#include "adc.h"
#include "audio.h"
#include "fifo.h"
#include "rtc.h"
#include "IR Remote.h"

void Hardware_Init(void);

enum ADC_Chs
{
	Audio_R1, Audio_L1, Audio_R0, Audio_L0, Buttons
};

#define IR_PORT			GPIOB
#define IR_PIN			PB1
#define IR_INP			(IR_PORT->IDR & (1<<IR_PIN))			

#define GPIOA_MODER (PIN_ALT(PA14)|PIN_ALT(PA13)|				/* SWCLK, SWDIO */	\
										 PIN_OUTPUT(PA10)|PIN_OUTPUT(PA9)|	/* CTRL1, CTRL0	*/	\
										 PIN_ALT(PA7)|PIN_OUTPUT(PA6)|			/* MOSI, D/C 		*/	\
										 PIN_ALT(PA5)|PIN_ANALOG(PA4)|			/* SCK ???			*/	\
										 PIN_ANALOG(PA3)|PIN_ANALOG(PA2)|		/* L0, R0				*/	\
		                 PIN_ANALOG(PA1)|PIN_ANALOG(PA0))		/* L1, R1				*/
										 
#define CTRL1				PA10
#define CTRL0				PA9

#define GPIOA_AFR1	 0


#endif

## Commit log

2016-07-05 Initial commit - add mainboard schematic/PCB
    [audio sw.brd, audio sw.sch]
2016-07-12 Added daughter card files and Sketchup 3D models
    [audio sw - daughter - rev 0.1.brd, audio sw - daughter - rev 0.1.sch, daughtercard-assembly.skp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]
2016-08-19 Relay version - initial bug fix - remove old files
    Relay version - initial bug fix1 - update new files
    Relay version - initial bug fix2 - remove non-source
    [Nokia5110.c, Nokia5110.h, adc.c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]
2016-08-22 Relay version - added Audio switching, bug fixes, updates Minor tweak for noisy relay circuit Bug fix - wrong define constants used. :( Change alti-alias filter to 18kHz + cleanup Update CAD files Up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
    [audio sw.brd, audio sw.sch]
2016-08-30 Tweaks for daughtercard Hardware updates
    [audio sw - daughter.brd, audio sw - daughter.sch, audio sw.brd]
2016-09-05 Enable Loudness Protection + BOM Consolidation
    [audio sw - daughter - rev 0.1.brd, audio sw - daughter - rev 0.1.sch]

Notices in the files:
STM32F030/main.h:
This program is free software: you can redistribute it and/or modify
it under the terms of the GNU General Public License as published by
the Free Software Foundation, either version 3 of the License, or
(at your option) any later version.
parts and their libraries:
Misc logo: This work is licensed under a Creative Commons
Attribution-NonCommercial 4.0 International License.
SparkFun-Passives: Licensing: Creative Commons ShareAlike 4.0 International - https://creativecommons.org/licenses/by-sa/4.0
